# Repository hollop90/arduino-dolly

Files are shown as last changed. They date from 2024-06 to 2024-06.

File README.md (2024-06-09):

# Arduino Dolly

A clone of the Arduino Nano, but a little different.

## Overview Image

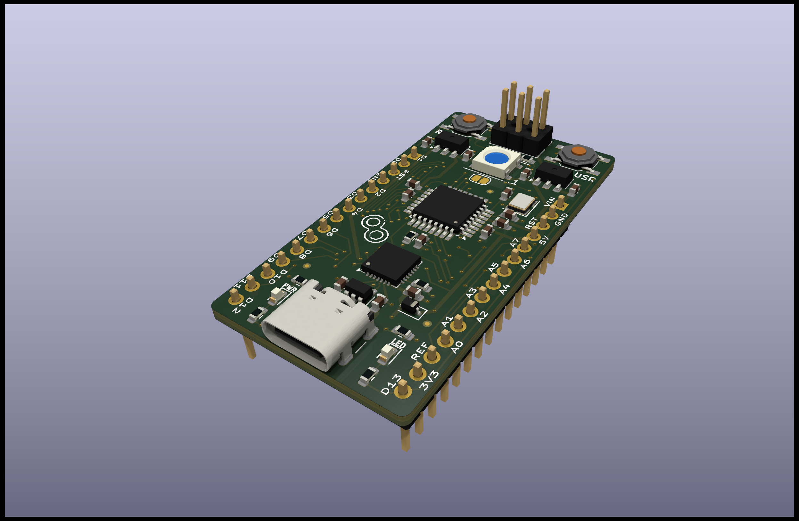
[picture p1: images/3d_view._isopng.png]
ISO


## Schematic

SCH

## 3D PCB

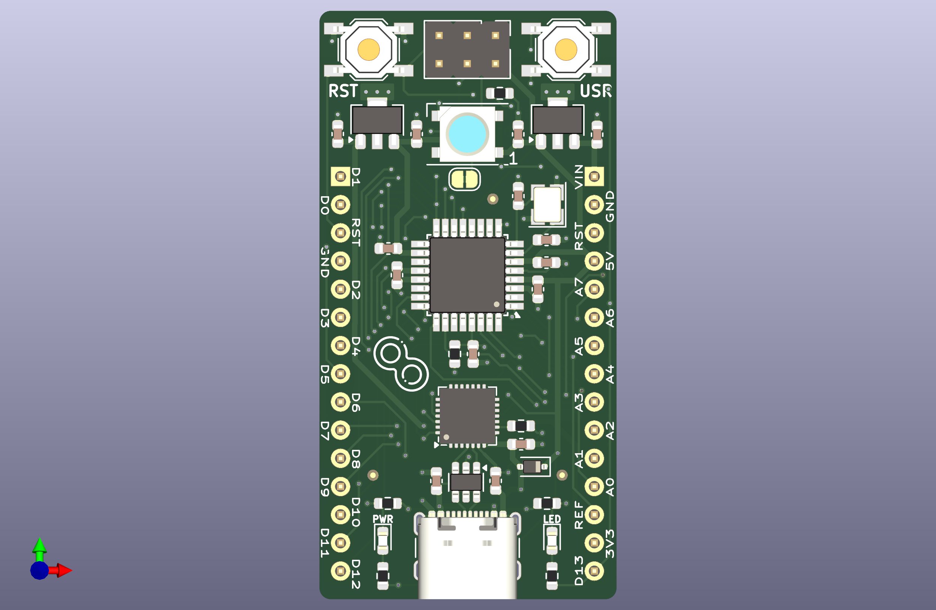
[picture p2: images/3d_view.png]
PCB


## Copper Layers

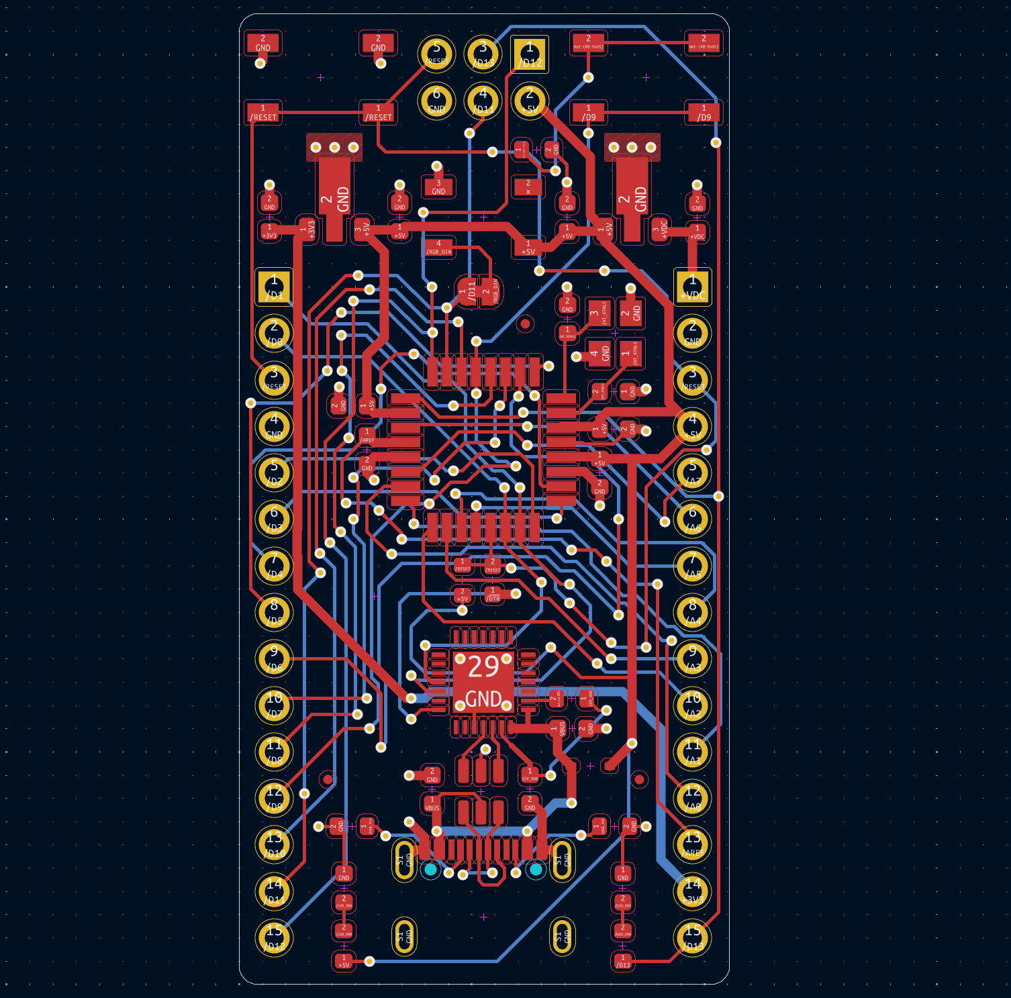
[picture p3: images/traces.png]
Cu


## todos

- [X] calculate crystal values
  - [X] calculate load capacitors - 12pf
  - [X] inspect layout - seems fine
- [X] Research USB TVS diodes
  - [X] the ones i'm using are probably not appropriate - yeah they are for RS485. FIXED
  - [X] look into what phils lab uses or the CATS board
- [X] Look into controlled impedance traces. NOT NEEDED
  - [X] calculate for the USB port. NOT DONE
- [X] Double check USB C layout
  - [X] ground the shilding
  - [X] series termination reistors? NAH
- [X] double check vreg capacitors. NEXT TIME USE 10u ON BOTH SIDES
- [X] check all capacitor dielectrics
- [X] add a fuse?. NO
- [X] review voltage selector diode. LGTM
- [X] Make a final BOM
- [X] Make production files
- [ ] Rip up traces and try alternete routing for MCU
- [X] CP2102 and others, what to do with unused pins

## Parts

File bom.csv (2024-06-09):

Reference | Value | Datasheet | Footprint | Qty | DNP | Description | JLCPCB Part #
J2 | USB_C_Receptacle_USB2.0_16P | https://wmsc.lcsc.com/wmsc/upload/file/pdf/v2/lcsc/2309181810_Lian-Xin-Technology-XUBF-0336-0817B_C7527694.pdf | Connector_USB:USB_C_Receptacle_GCT_USB4105-xx-A_16P_TopMnt_Horizontal | 1 |  | USB 2.0-only 16P Type-C Receptacle connector | C7527694
D3 | WS2812B | https://wmsc.lcsc.com/wmsc/upload/file/pdf/v2/lcsc/2404120946_XINGLIGHT-XL-5050RGBC-WS2812B_C2843785.pdf | LED_SMD:LED_WS2812B_PLCC4_5.0x5.0mm_P3.2mm | 1 |  | RGB LED with integrated controller | C2843785
SW1,SW2 | Push Button | https://wmsc.lcsc.com/wmsc/upload/file/pdf/v2/lcsc/2304140030_XKB-Connection-TS-1187A-B-A-B_C318884.pdf | Button_Switch_SMD:SW_SPST_TL3342 | 2 |  | Push button switch, generic, two pins | C318884
D1 | 1N5819WS | https://wmsc.lcsc.com/wmsc/upload/file/pdf/v2/lcsc/2204281430_Guangdong-Hottech-1N5819WS_C191023.pdf | Diode_SMD:D_SOD-323 | 1 |  | Schottky diode | C191023
U1 | 78L05G-AB3-R | https://wmsc.lcsc.com/wmsc/upload/file/pdf/v2/lcsc/2304140030_UTC-Unisonic-Tech-78L05G-AB3-R_C71136.pdf | Package_TO_SOT_SMD:SOT-89-3 | 1 |  | Positive 100mA 30V Linear Regulator, Fixed Output 5V, SOT-89 | C71136
C8,C9 | 12p | https://wmsc.lcsc.com/wmsc/upload/file/pdf/v2/lcsc/2304140030_Samsung-Electro-Mechanics-CL10C120JB8NNNC_C38523.pdf | Capacitor_SMD:C_0603_1608Metric | 2 |  | Unpolarized capacitor, small symbol | C38523
R3,R4 | 5k1 | https://wmsc.lcsc.com/wmsc/upload/file/pdf/v2/lcsc/2206010116_UNI-ROYAL-Uniroyal-Elec-0603WAF5101T5E_C23186.pdf | Resistor_SMD:R_0603_1608Metric | 2 |  | Resistor, small symbol | C23186
R1,R2,R7,R8,R9 | 1k | https://wmsc.lcsc.com/wmsc/upload/file/pdf/v2/lcsc/2206010130_UNI-ROYAL-Uniroyal-Elec-0603WAF1001T5E_C21190.pdf | Resistor_SMD:R_0603_1608Metric | 5 |  | Resistor, small symbol | C21190
C1,C3 | 10u | https://wmsc.lcsc.com/wmsc/upload/file/pdf/v2/lcsc/2304140030_Samsung-Electro-Mechanics-CL10A106KP8NNNC_C19702.pdf | Capacitor_SMD:C_0603_1608Metric | 2 |  | Unpolarized capacitor | C19702
U3 | ATmega328P-A | http://ww1.microchip.com/downloads/en/DeviceDoc/ATmega328_P%20AVR%20MCU%20with%20picoPower%20Technology%20Data%20Sheet%2040001984A.pdf | Package_QFP:TQFP-32_7x7mm_P0.8mm | 1 |  | 20MHz, 32kB Flash, 2kB SRAM, 1kB EEPROM, TQFP-32 | C14877
C2,C4,C5,C6,C7,C10,C11,C12,C13,C15 | 100n | https://wmsc.lcsc.com/wmsc/upload/file/pdf/v2/lcsc/2211101700_YAGEO-CC0603KRX7R9BB104_C14663.pdf | Capacitor_SMD:C_0603_1608Metric | 10 |  | -- mixed values -- | C14663
U2 | HT7533-1 | https://wmsc.lcsc.com/wmsc/upload/file/pdf/v2/lcsc/2312191111_Holtek-Semicon-HT7533-1_C14289.pdf | Package_TO_SOT_SMD:SOT-89-3 | 1 |  | Positive 100mA 30V Linear Regulator, Fixed Output 3.3V, SOT-89 | C14289
Y1 | 16 MHz | https://wmsc.lcsc.com/wmsc/upload/file/pdf/v2/lcsc/2403291504_YXC-X322516MLB4SI_C13738.pdf | Crystal:Crystal_SMD_3225-4Pin_3.2x2.5mm | 1 |  | Four pin crystal, GND on pins 2 and 4 | C13738
U4 | CP2102-GMR | https://wmsc.lcsc.com/wmsc/upload/file/pdf/v2/lcsc/1811081920_SKYWORKS-SILICON-LABS-CP2102-GMR_C6568.pdf | Package_DFN_QFN:QFN-28-1EP_5x5mm_P0.5mm_EP3.35x3.35mm | 1 |  | USB to UART master bridge, QFN-28 | C6568
D2,D4 | RED | https://wmsc.lcsc.com/wmsc/upload/file/pdf/v2/lcsc/1810231112_Hubei-KENTO-Elec-KT-0603R_C2286.pdf | LED_SMD:LED_0603_1608Metric | 2 |  | Light emitting diode, small symbol | C2286
U5 | USBLC6-2SC6 | https://www.st.com/resource/en/datasheet/usblc6-2.pdf | Package_TO_SOT_SMD:SOT-23-6 | 1 |  | Very low capacitance ESD protection diode, 2 data-line, SOT-23-6
J4 | 2x3 Pin Header | ~ | Connector_PinHeader_2.54mm:PinHeader_2x03_P2.54mm_Vertical | 1 |  | Generic connector, double row, 02x03, counter clockwise pin numbering scheme (similar to DIP package numbering), script generated (kicad-library-utils/schlib/autogen/connector/)
J1,J3 | 1x15 Pin Header | ~ | Connector_PinHeader_2.54mm:PinHeader_1x15_P2.54mm_Vertical | 2 |  | Generic connector, single row, 01x15, script generated (kicad-library-utils/schlib/autogen/connector/)

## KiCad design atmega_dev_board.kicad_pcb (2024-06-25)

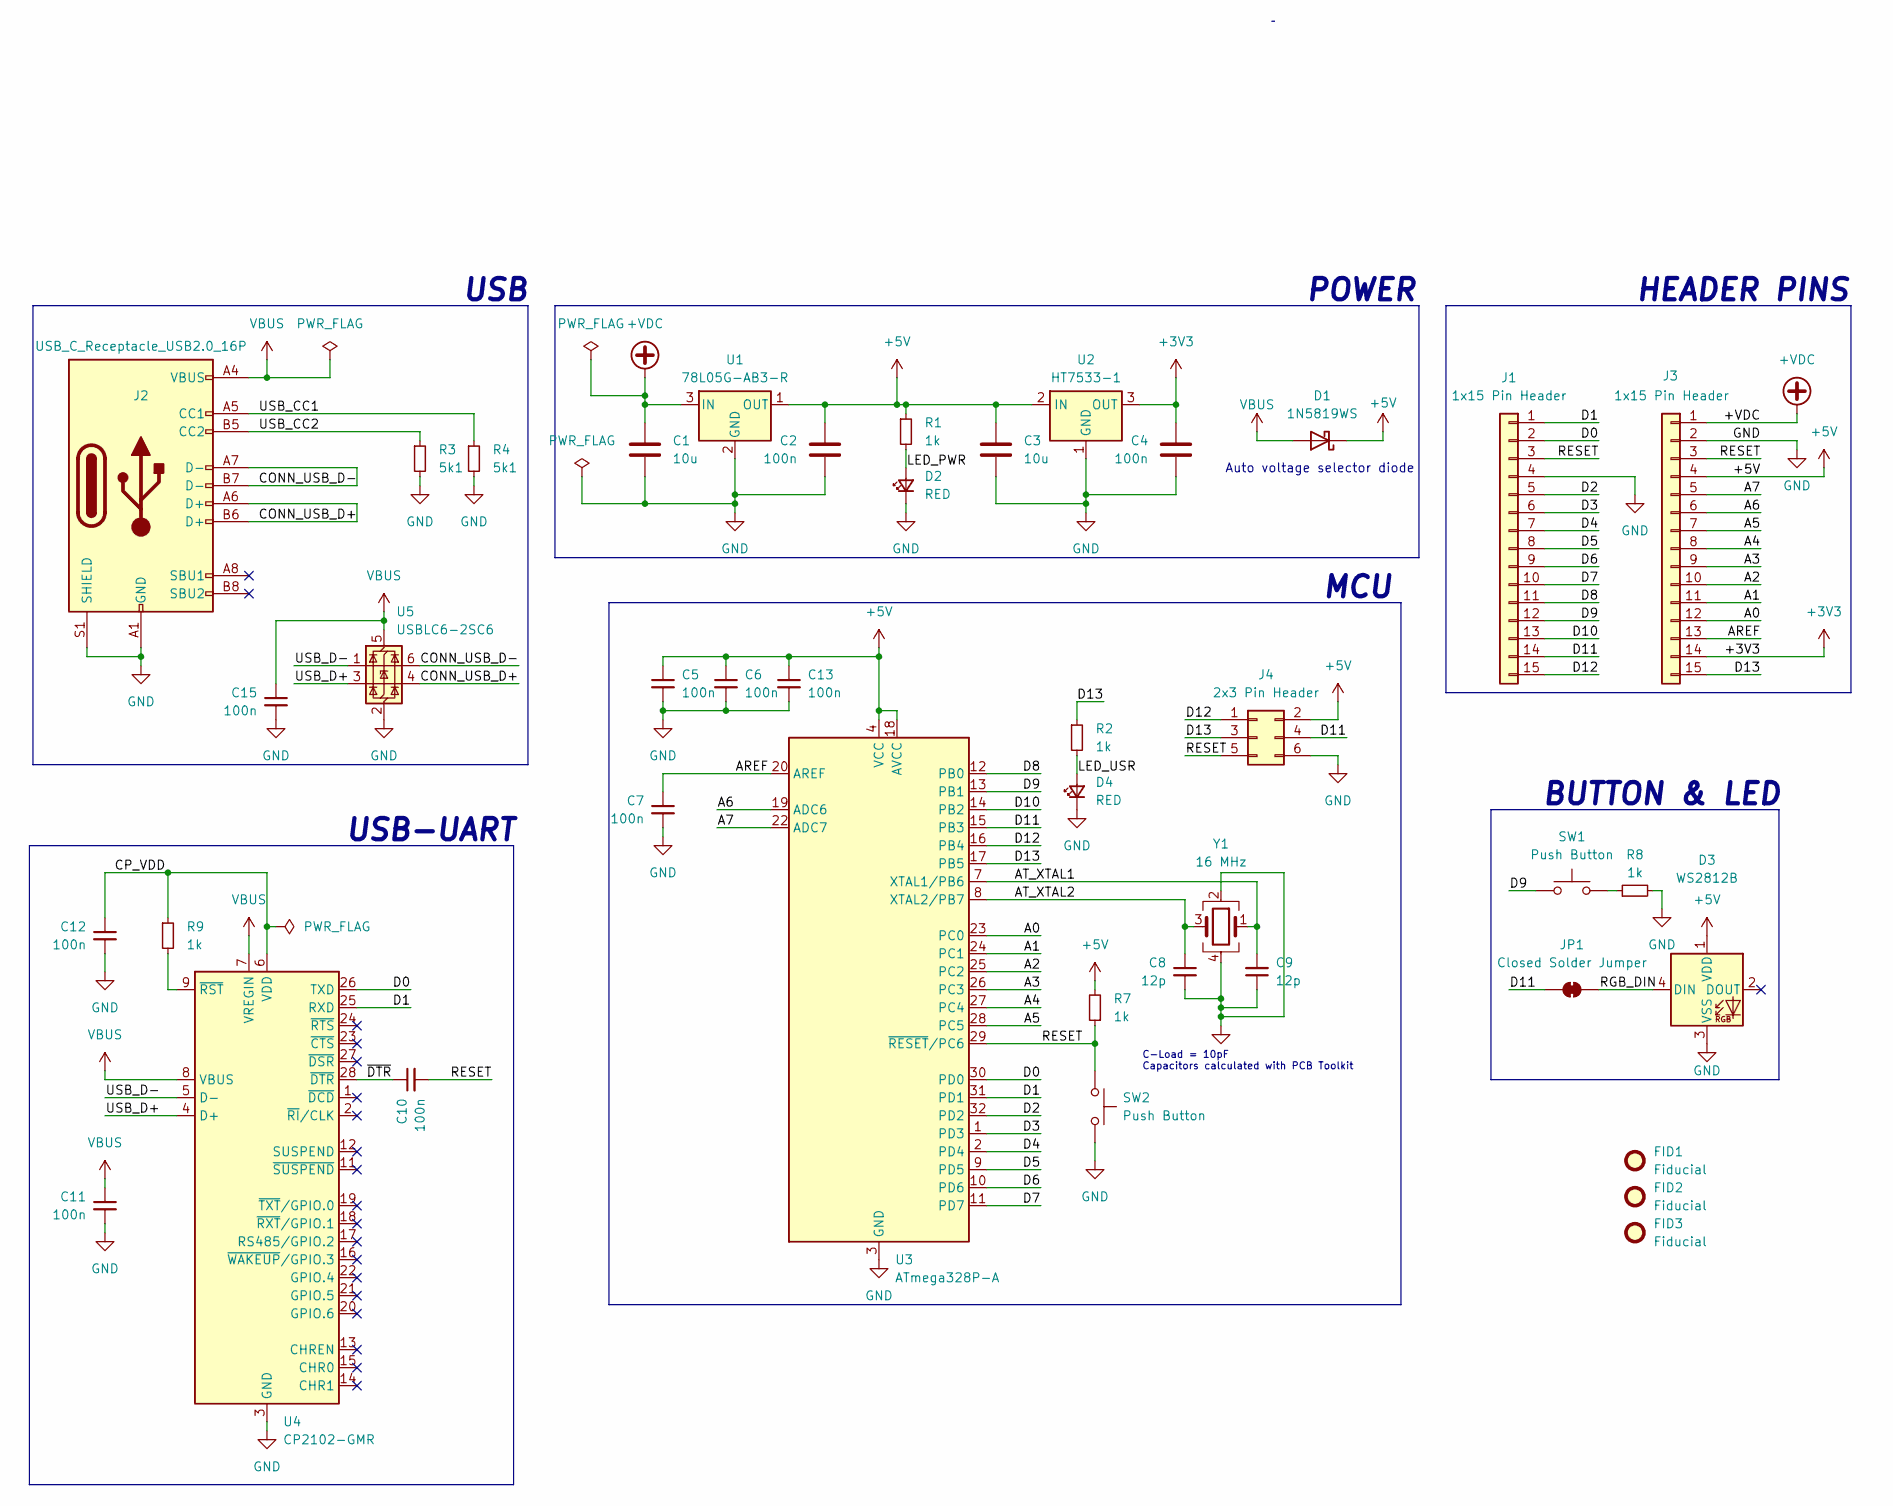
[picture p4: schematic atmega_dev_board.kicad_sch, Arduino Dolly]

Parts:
C1, C3: 10u; C_0603_1608Metric; Manufacturer Part# CL10A106KP8NNNC; JLCPCB Part # C19702
C2, C4, C5, C6, C7, C10, C11, C12, C13, C15: 100n; C_0603_1608Metric; Manufacturer Part# CC0603KRX7R9BB104; JLCPCB Part # C14663
C8, C9: 12p; C_0603_1608Metric; Manufacturer Part# CL10C120JB8NNNC; JLCPCB Part # C38523
D1: 1N5819WS; D_SOD-323; Manufacturer Part# 1N5819WS; JLCPCB Part # C191023
D2, D4: RED; LED_0603_1608Metric; Manufacturer Part# KT-0603R; JLCPCB Part # C2286
D3: WS2812B; LED_WS2812B_PLCC4_5.0x5.0mm_P3.2mm; Manufacturer Part# XL-5050RGBC-WS2812B; JLCPCB Part # C2843785
FID1, FID2, FID3: Fiducial; Fiducial_0.5mm_Mask1mm
J1, J3: 1x15 Pin Header; PinHeader_1x15_P2.54mm_Vertical
J2: USB_C_Receptacle_USB2.0_16P; USB_C_Receptacle_GCT_USB4105-xx-A_16P_TopMnt_Horizontal; Manufacturer Part# XUBF-0336-0817B; JLCPCB Part # C7527694
J4: 2x3 Pin Header; PinHeader_2x03_P2.54mm_Vertical
JP1: Closed Solder Jumper; SolderJumper-2_P1.3mm_Bridged_RoundedPad1.0x1.5mm
R1, R2, R7, R8, R9: 1k; R_0603_1608Metric; Manufacturer Part# 0603WAF1001T5E; JLCPCB Part # C21190
R3, R4: 5k1; R_0603_1608Metric; Manufacturer Part# 0603WAF5101T5E; JLCPCB Part # C23186
SW1, SW2: Push Button; SW_SPST_TL3342; Manufacturer Part# TS-1187A-B-A-B; JLCPCB Part # C318884
U1: 78L05G-AB3-R; SOT-89-3; Manufacturer Part# 78L05G-AB3-R; JLCPCB Part # C71136
U2: HT7533-1; SOT-89-3; Manufacturer Part# HT7533-1; JLCPCB Part # C14289
U3: ATmega328P-A; TQFP-32_7x7mm_P0.8mm; Manufacturer Part# ATMEGA328P-AU; JLCPCB Part # C14877
U4: CP2102-GMR; QFN-28-1EP_5x5mm_P0.5mm_EP3.35x3.35mm; Manufacturer Part# CP2102-GMR; JLCPCB Part # C6568
U5: USBLC6-2SC6; SOT-23-6
Y1: 16 MHz; Crystal_SMD_3225-4Pin_3.2x2.5mm; Manufacturer Part# X322516MLB4SI; JLCPCB Part # C13738

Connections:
+3V3: C4.1, J3.14, U2.3 (OUT)
+5V: C2.1, C3.1, C5.1, C6.1, C13.1, D1.1 (K), D3.1 (VDD), J3.4, J4.2, R1.1, R7.2, U1.1 (OUT), U2.2 (IN), U3.4 (VCC), U3.6 (VCC), U3.18 (AVCC)
+VDC: C1.1, J3.1, U1.3 (IN)
/A0: J3.12, U3.23 (PC0)
/A1: J3.11, U3.24 (PC1)
/A2: J3.10, U3.25 (PC2)
/A3: J3.9, U3.26 (PC3)
/A4: J3.8, U3.27 (PC4)
/A5: J3.7, U3.28 (PC5)
/A6: J3.6, U3.19 (ADC6)
/A7: J3.5, U3.22 (ADC7)
/AREF: C7.1, J3.13, U3.20 (AREF)
/AT_XTAL1: C9.2, U3.7 (XTAL1/PB6), Y1.1
/AT_XTAL2: C8.1, U3.8 (XTAL2/PB7), Y1.3
/CONN_USB_D+: J2.A6 (D+), J2.B6 (D+), U5.4 (I/O2)
/CONN_USB_D-: J2.A7 (D-), J2.B7 (D-), U5.6 (I/O1)
/CP_VDD: C12.1, R9.1, U4.6 (VDD)
/D0: J1.2, U3.30 (PD0), U4.26 (TXD)
/D1: J1.1, U3.31 (PD1), U4.25 (RXD)
/D2: J1.5, U3.32 (PD2)
/D3: J1.6, U3.1 (PD3)
/D4: J1.7, U3.2 (PD4)
/D5: J1.8, U3.9 (PD5)
/D6: J1.9, U3.10 (PD6)
/D7: J1.10, U3.11 (PD7)
/D8: J1.11, U3.12 (PB0)
/D9: J1.12, SW1.1, U3.13 (PB1)
/D10: J1.13, U3.14 (PB2)
/D11: J1.14, J4.4, JP1.1 (A), U3.15 (PB3)
/D12: J1.15, J4.1, U3.16 (PB4)
/D13: J3.15, J4.3, R2.1, U3.17 (PB5)
/LED_PWR: D2.2 (A), R1.2
/LED_USR: D4.2 (A), R2.2
/RESET: C10.2, J1.3, J3.3, J4.5, R7.1, SW2.1, U3.29 (~RESET/PC6)
/RGB_DIN: D3.4 (DIN), JP1.2 (B)
/USB_CC1: J2.A5 (CC1), R4.1
/USB_CC2: J2.B5 (CC2), R3.1
/USB_D+: U4.4 (D+), U5.3 (I/O2)
/USB_D-: U4.5 (D-), U5.1 (I/O1)
/~DTR: C10.1, U4.28 (~DTR)
GND: C1.2, C2.2, C3.2, C4.2, C5.2, C6.2, C7.2, C8.2, C9.1, C11.2, C12.2, C13.2, C15.2, D2.1 (K), D3.3 (VSS), D4.1 (K), J1.4, J2.A1 (GND), J2.A12 (GND), J2.B1 (GND), J2.B12 (GND), J2.S1 (SHIELD), J3.2, J4.6, R3.2, R4.2, R8.2, SW2.2, U1.2 (GND), U2.1 (GND), U3.3 (GND), U3.5 (GND), U3.21 (GND), U4.3 (GND), U4.29 (GND), U5.2 (GND), Y1.2, Y1.4
unnamed: R8.1, SW1.2
unnamed: R9.2, U4.9 (~RST)
VBUS: C11.1, C15.1, D1.2 (A), J2.A4 (VBUS), J2.A9 (VBUS), J2.B4 (VBUS), J2.B9 (VBUS), U4.7 (VREGIN), U4.8 (VBUS), U5.5 (VBUS)

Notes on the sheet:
Auto voltage selector diode
MCU
POWER
HEADER PINS
C-Load = 10pF Capacitors calculated with PCB Toolkit
USB
BUTTON & LED
USB-UART

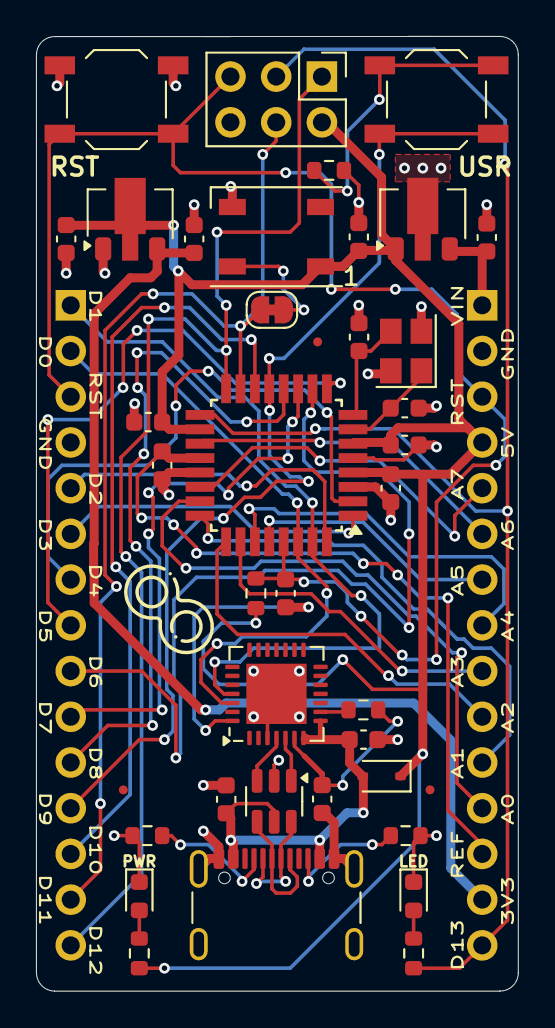
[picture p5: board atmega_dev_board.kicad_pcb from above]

Board: 4 copper layers, 26.8 x 53.0 mm, 41 parts (0 on the bottom side), 44 nets.

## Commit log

2024-05-26 init commit
    [atmega_dev_board.kicad_pcb, atmega_dev_board.kicad_sch]
2024-05-26 Replace op-amps with a diode
    [atmega_dev_board.kicad_sch]
2024-05-26 Replace voltage regulators with 78XXs
    [atmega_dev_board.kicad_sch]
2024-05-27 Move to USB C and CP2102
    [atmega_dev_board.kicad_pcb, atmega_dev_board.kicad_sch, bom.csv]
2024-05-28 Adjust pin header and board size to match 0m1" pitch
    [atmega_dev_board.kicad_pcb]
2024-05-28 New placements of PCB
    [atmega_dev_board.kicad_pcb]
2024-05-28 Tidy up schema and route all but GPIO traces
    [atmega_dev_board.kicad_pcb, atmega_dev_board.kicad_sch]
2024-05-29 Update PCB meta data. More GPIO routing
    [atmega_dev_board.kicad_pcb]
2024-06-02 Finish routing, update design rules
    [atmega_dev_board.kicad_pcb]
2024-06-02 Update revision number and date
    [atmega_dev_board.kicad_sch]
2024-06-03 Update loading cap values (from 22p to 12p)
    [atmega_dev_board.kicad_sch]
2024-06-03 Swap out TVS diodes. Ground USB shield
    [atmega_dev_board.kicad_pcb, atmega_dev_board.kicad_sch]
2024-06-03 Update BOM and component values
    [atmega_dev_board.kicad_pcb, atmega_dev_board.kicad_sch, bom.csv]
2024-06-04 lots
    Sch: Add feducials
    PCB: Add pin labels to silkscreen
    [atmega_dev_board.kicad_pcb, atmega_dev_board.kicad_sch]
2024-06-04 Add pull up R to RESET. Add current limiting R to USR button
    [atmega_dev_board.kicad_pcb, atmega_dev_board.kicad_sch]
2024-06-05 Finishing touches
    ## PCB
    * Tighten zone clearance from 0.5 to 0.2
    * Add silkscreen (names and logos)
    * Reposition LEDs
    * Round corners
    * Remove unecessaary components
    ## SCH
    * Remove extra 10 USB cap
    * Remove unecessaary components
    [atmega_dev_board.kicad_pcb, atmega_dev_board.kicad_sch]
2024-06-05 Fix via sizing and other small changes
    * Update part numbers
    * Update BOM
    * Slight fixes to schematic
    [atmega_dev_board.kicad_pcb, atmega_dev_board.kicad_sch, bom.csv]
2024-06-09 Update BOM
    [atmega_dev_board.kicad_pcb, bom.csv]
2024-06-25 fix: Fix UART mis-match. Fix VREG footprint
    [atmega_dev_board.kicad_pcb, atmega_dev_board.kicad_sch]
2024-09-23 fix: Update schematic svg to reflect project changes
